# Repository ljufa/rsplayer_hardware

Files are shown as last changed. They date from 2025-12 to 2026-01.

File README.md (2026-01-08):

# RSPlayer Hardware

This repository contains the hardware design files for the RSPlayer project, a high-quality audio player. The designs are created in KiCad.

## Design Philosophy

This hardware design prioritizes **modularity** and **DIY-friendliness**. The goal is to provide a flexible platform where enthusiasts can easily swap components, upgrade specific subsystems (like power regulators or output stages), and experiment with different configurations. This open architecture encourages users to tweak the design, test new ideas, and continuously improve the audio performance to match their personal preferences.

## Boards
This repository is structured into several directories, each containing a specific board or a set of related files:

- **control_board_with_amanero**: A control board featuring an Amanero Combo768 USB interface.
- **lpf_ak4497**: Low-pass filter boards designed for the AK4497 DAC datasheet schematics. It includes designs for both `dual` and `dual_mono` configurations.
- [**LT3045_breakout**](https://github.com/PatrickBaus/LT3045_breakout.git): A modular breakout board for LT3042/LT3045 ultra-low noise regulators, used as drop-in replacements for 78xx series regulators.
- [**rsplayer_hardware_docs_private**](https://github.com/ljufa/rsplayer_hardware_docs_private.git): Contains external datasheets for various components used in the project. (this is private due to copyright)
- **MyLibrary.pretty**: A custom KiCad footprint library for this project.

## Features & Benefits

### Core Control & Interface
*   **MCU:** Powered by the **Raspberry Pi Pico (RP2040)**, providing robust system management, user interface control, and configuration logic. [**Firmware is here**](https://github.com/ljufa/rsplayer_firmware.git). 
*   **USB Audio:** Dedicated socket for **Amanero Combo384/Combo768** USB interfaces, supporting high-resolution PCM and DSD playback.
*   **User Interface:** Supports a Rotary Encoder for volume/navigation, IR Receiver (TSOP312) for remote control, and headers for LCD/OLED display integration.

### High-Fidelity Audio Design
*   **Galvanic Isolation:** Full isolation between the digital control logic (Pico/USB) and the sensitive DAC/Audio circuitry. Uses high-speed isolators (e.g., IL715E, ADuM1250) to eliminate ground loops and prevent digital noise from affecting audio quality.
*   **Hardware Muting:** Relay-based output muting protection to prevent audible pops and clicks during power cycles or sample rate changes.
*   **I2S Source Switching:** Features an intelligent I2S switching circuit using dual **74AC573** Octal Latches. This setup acts as a high-speed multiplexer, allowing seamless selection between the **Amanero USB interface (Source B)** and the **Optical/TOSLINK Input (Source A)**, controlled directly by the Raspberry Pi Pico.
*   **I2S & DSD Support:** Native handling of I2S and DSD signals routed directly to the DAC interface.

### Advanced Power Management
*   **Ultra-Low Noise Regulation:** Critically sensitive DAC stages are powered by modular **LT3042/LT3045** regulators. These are implemented as separate breakout boards (based on the `LT3045_breakout` design) acting as high-performance drop-in replacements for standard regulators, providing industry-leading low noise (0.8µVrms) and ultra-high PSRR.
*   **Multi-Rail Linear PSU:** On-board rectification and regulation generating separate clean rails for digital (3.3V), analog, and op-amp stages.
*   **Smart Power Control:** Relay-controlled AC mains switching allows for standby modes and remote power-on capabilities.

## Schematics
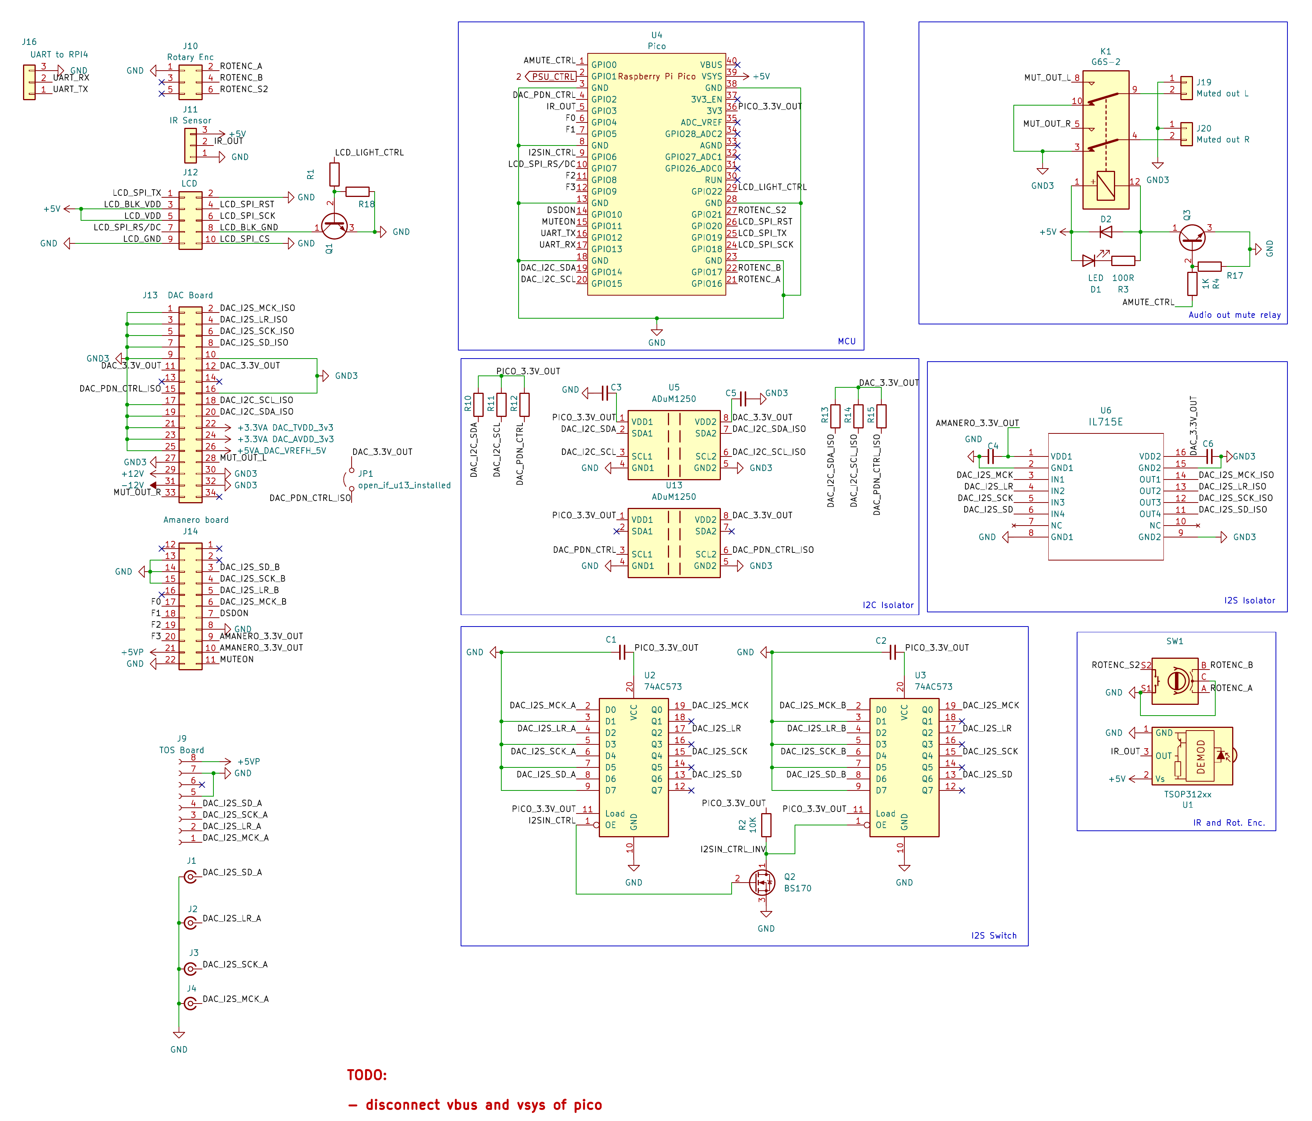
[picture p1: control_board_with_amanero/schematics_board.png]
Schematic Page 1

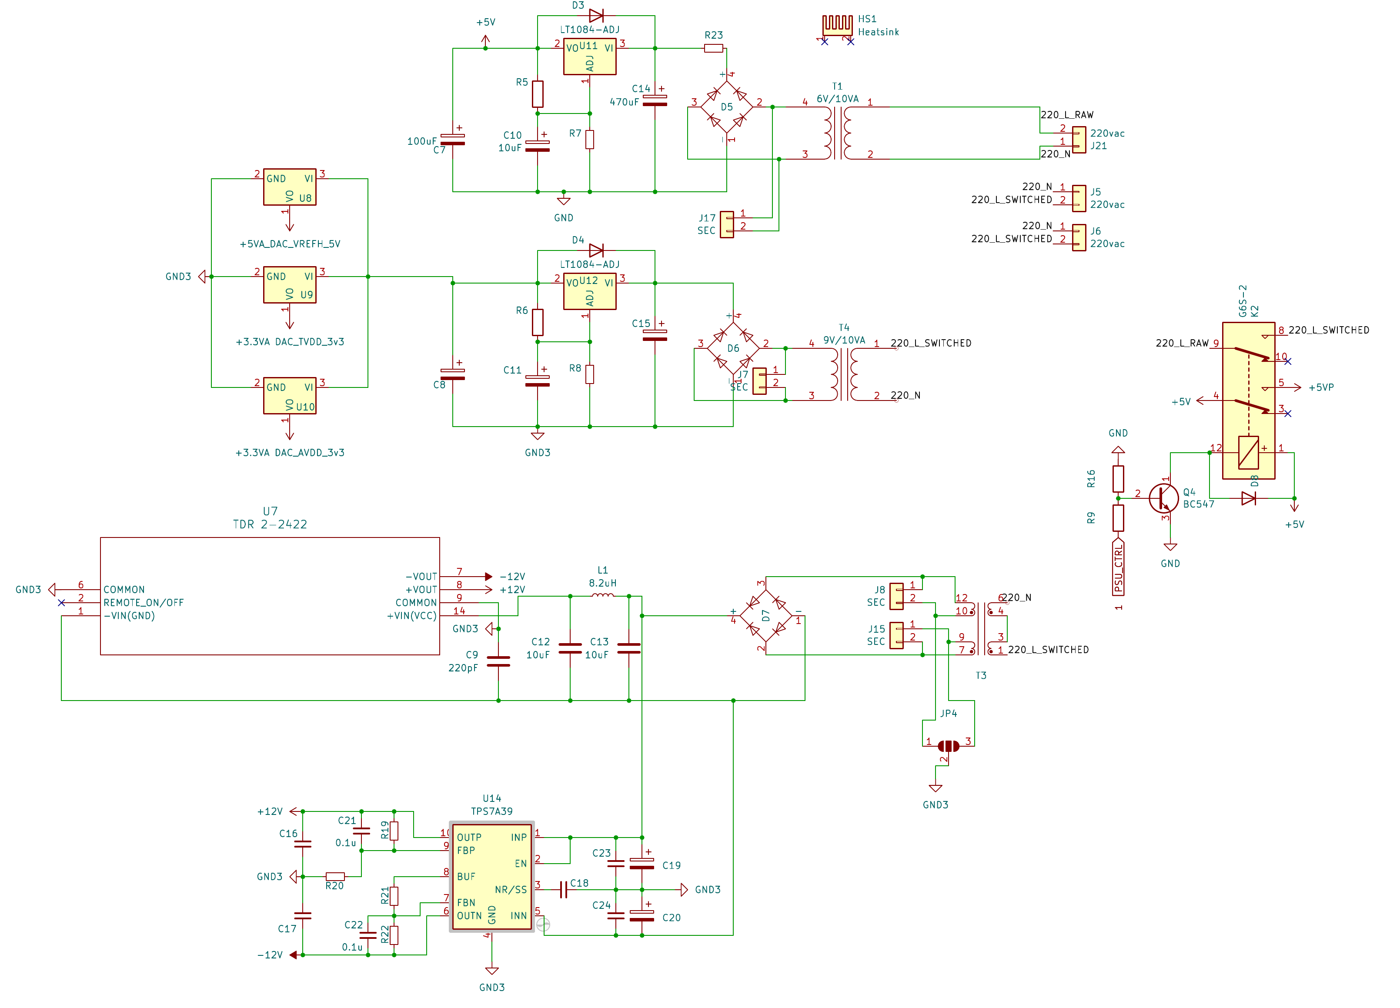
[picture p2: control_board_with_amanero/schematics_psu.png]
Schematic Page 2


## PCB
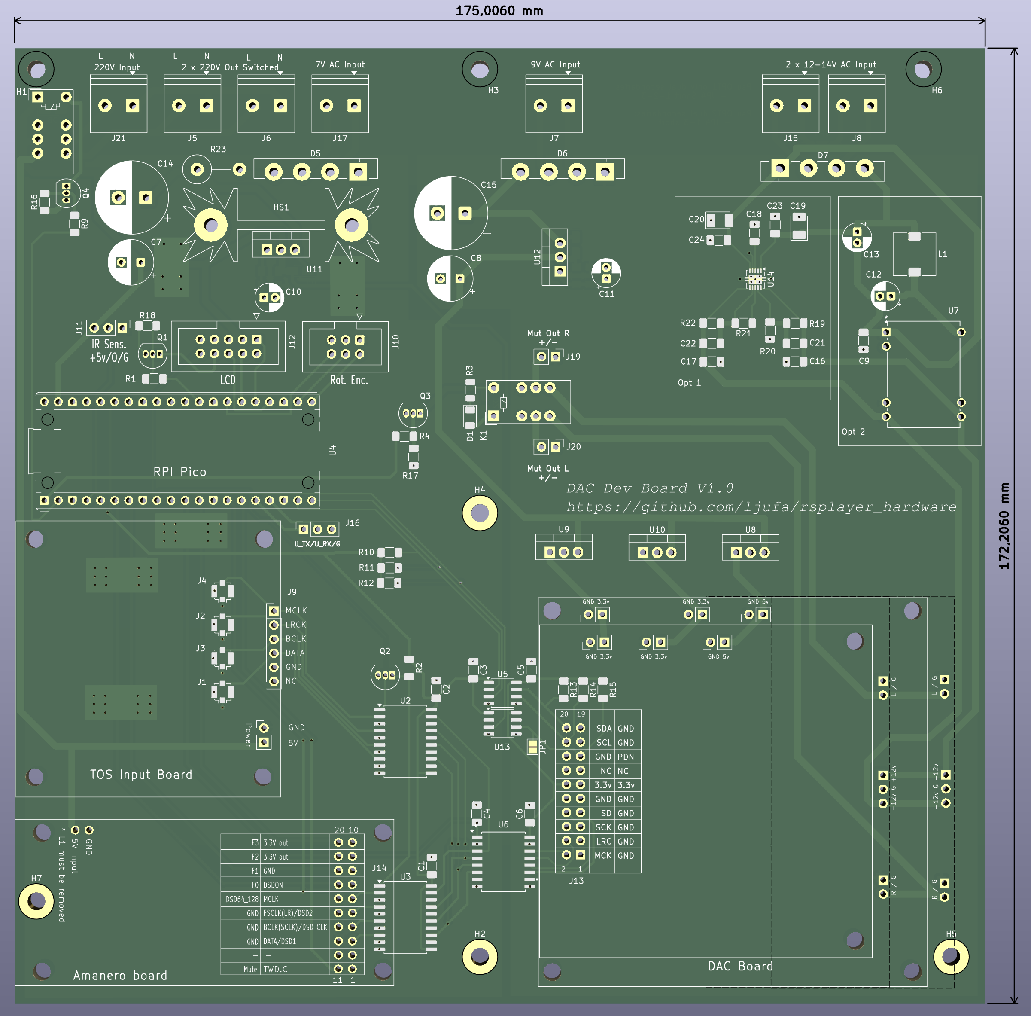
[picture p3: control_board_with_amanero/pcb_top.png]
top

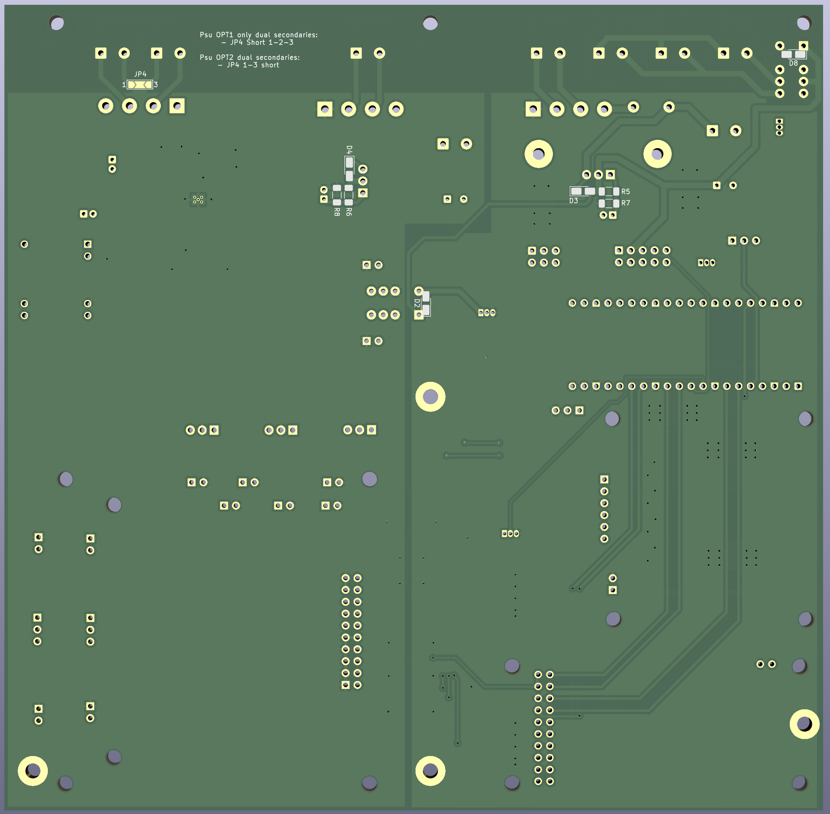
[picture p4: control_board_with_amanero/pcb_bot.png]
bottom

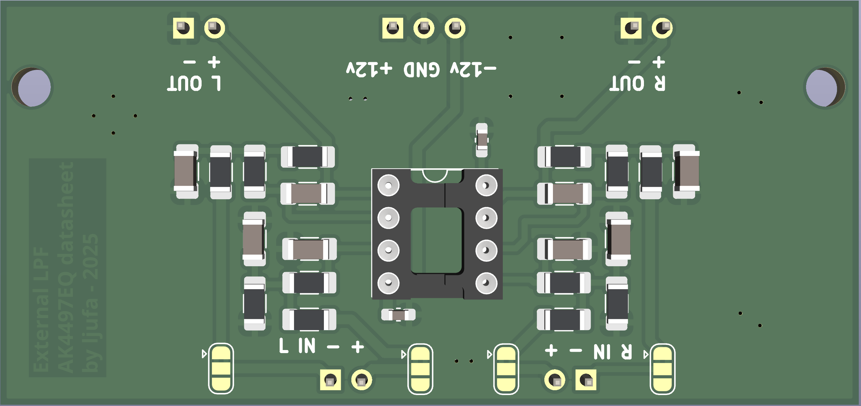
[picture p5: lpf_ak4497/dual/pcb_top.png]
lpf_top

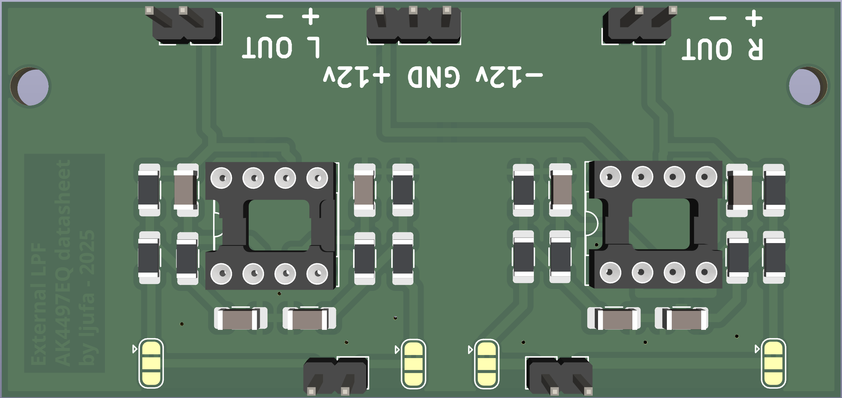
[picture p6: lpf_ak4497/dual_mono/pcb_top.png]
lpf_dm_top

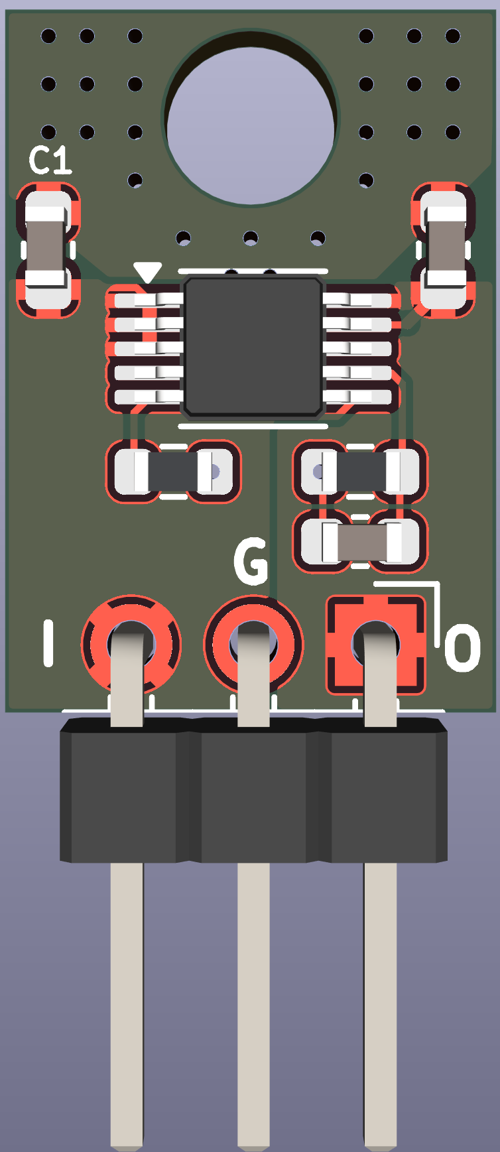
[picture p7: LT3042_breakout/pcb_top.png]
lt3042_top


## Future Roadmap
The project is evolving to become a universal high-fidelity audio platform. Planned improvements include:
*   **Expanded Interface Support:** Adding compatibility for additional **USB-to-I2S** boards beyond the Amanero series.
*   **Universal DAC Support:** Developing adapters and firmware logic to support a wider variety of **DAC chips and boards** (e.g., ESS Sabre, Burr-Brown), allowing users to choose their preferred sound signature.

## Related Projects
The RSPlayer is a multi-repository project:

- [**rsplayer**](https://github.com/ljufa/rsplayer.git): The main music player software running on PC or SBC.
- [**rsplayer_firmware**](https://github.com/ljufa/rsplayer_firmware.git): Firmware for MCU on this board. 

## License
This project is licensed under the MIT License. See the [LICENSE](LICENSE) file for details.

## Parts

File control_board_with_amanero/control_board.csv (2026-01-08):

Reference | Value | Qty
C1,C2,C3,C4,C5,C6,C21,C22,C23,C24 | 0.1u | 10
C7,C8 | 100uF | 2
C9 | 220pF | 1
C10,C11,C12,C13 | 10uF | 4
C14,C15 | 470uF | 2
C16,C17 | Value=22uF | 2
C18 | Value=10nF | 1
C19,C20 | Value=33uF Rser=350m | 2
D1 | LED | 1
D2,D3,D4,D8 | 1N4004 | 4
D5,D6,D7 | B80C3x00-2200A | 3
H1,H3,H6 | ~ | 3
HS1 | Heatsink | 1
J1,J2,J3,J4 | Conn_Coaxial_Small | 4
J5,J6,J21 | 220vac | 3
J7,J8,J15,J17 | SEC | 4
J9 | TOS Board | 1
J10 | Rotary Enc | 1
J11 | IR Sensor | 1
J12 | LCD | 1
J13 | DAC Board | 1
J14 | Amanero board | 1
J16 | UART to RPI4 | 1
J19 | Muted out L | 1
J20 | Muted out R | 1
JP1 | open_if_u13_installed | 1
K1,K2 | G6S-2 | 2
L1 | 8.2uH | 1
Q1,Q3,Q4 | BC547 | 3
Q2 | BS170 | 1
R1,R4,R9 | 1K | 3
R2,R10,R11,R12,R13,R14,R15,R16,R17,R18 | 10K | 10
R3,R5,R6 | 100R | 3
R7 | 300R | 1
R8 | 470R | 1
R19 | 90.9K | 1
R20,R21 | 10k | 2
R22 | 100k | 1
R23 | 0R | 1
SW1 | RotaryEncoder_Switch | 1
T1 | 6V/10VA | 1
T3 | Triad_VPP16-310 | 1
T4 | 9V/10VA | 1
U1 | TSOP312xx | 1
U2,U3 | 74AC573 | 2
U4 | Pico | 1
U5,U13 | ADuM1250 | 2
U6 | IL715E | 1
U7 | TDR 2-2422 | 1
U8,U9,U10 | lt3042_breakout | 3
U11,U12 | LT1084-ADJ | 2
U14 | TPS7A39 | 1

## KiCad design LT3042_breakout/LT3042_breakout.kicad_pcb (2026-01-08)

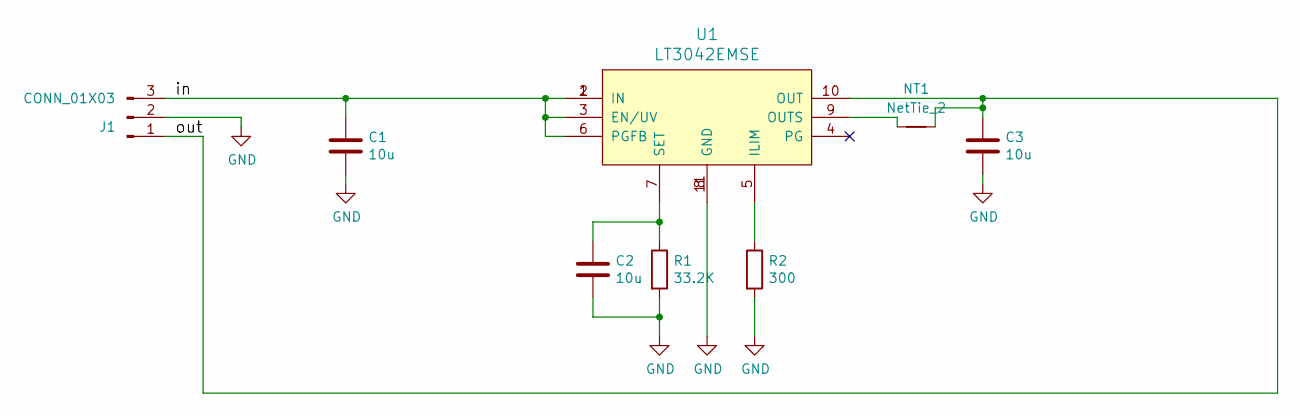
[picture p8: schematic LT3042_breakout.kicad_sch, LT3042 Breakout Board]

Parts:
C1, C2, C3: 10u; C_0603_1608Metric
J1: CONN_01X03; PinHeader_1x03_P2.54mm_Horizontal
NT1: NetTie_2; NetTie-2_SMD_Pad0.2mm
R1: 33.2K; R_0603_1608Metric
R2: 300; R_0603_1608Metric
U1: LT3042EMSE; MSOP-10-1EP_3x3mm_P0.5mm_EP1.68x1.88mm_ThermalVias

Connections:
/in: C1.1, J1.3, U1.1 (IN), U1.2 (IN), U1.3 (EN/UV), U1.6 (PGFB)
/out: C3.1, J1.1, NT1.2, U1.10 (OUT)
GND: C1.2, C2.2, C3.2, J1.2, R1.2, R2.2, U1.8 (GND), U1.11
unnamed: R2.1, U1.5 (ILIM)
unnamed: NT1.1, U1.9 (OUTS)
unnamed: C2.1, R1.1, U1.7 (SET)

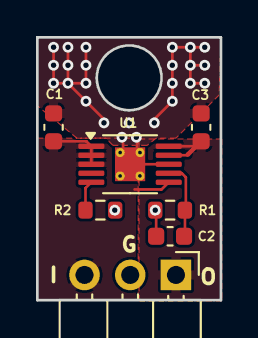
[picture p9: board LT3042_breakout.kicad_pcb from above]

Board: 2 copper layers, 10.2 x 14.6 mm, 8 parts (0 on the bottom side), 6 nets.

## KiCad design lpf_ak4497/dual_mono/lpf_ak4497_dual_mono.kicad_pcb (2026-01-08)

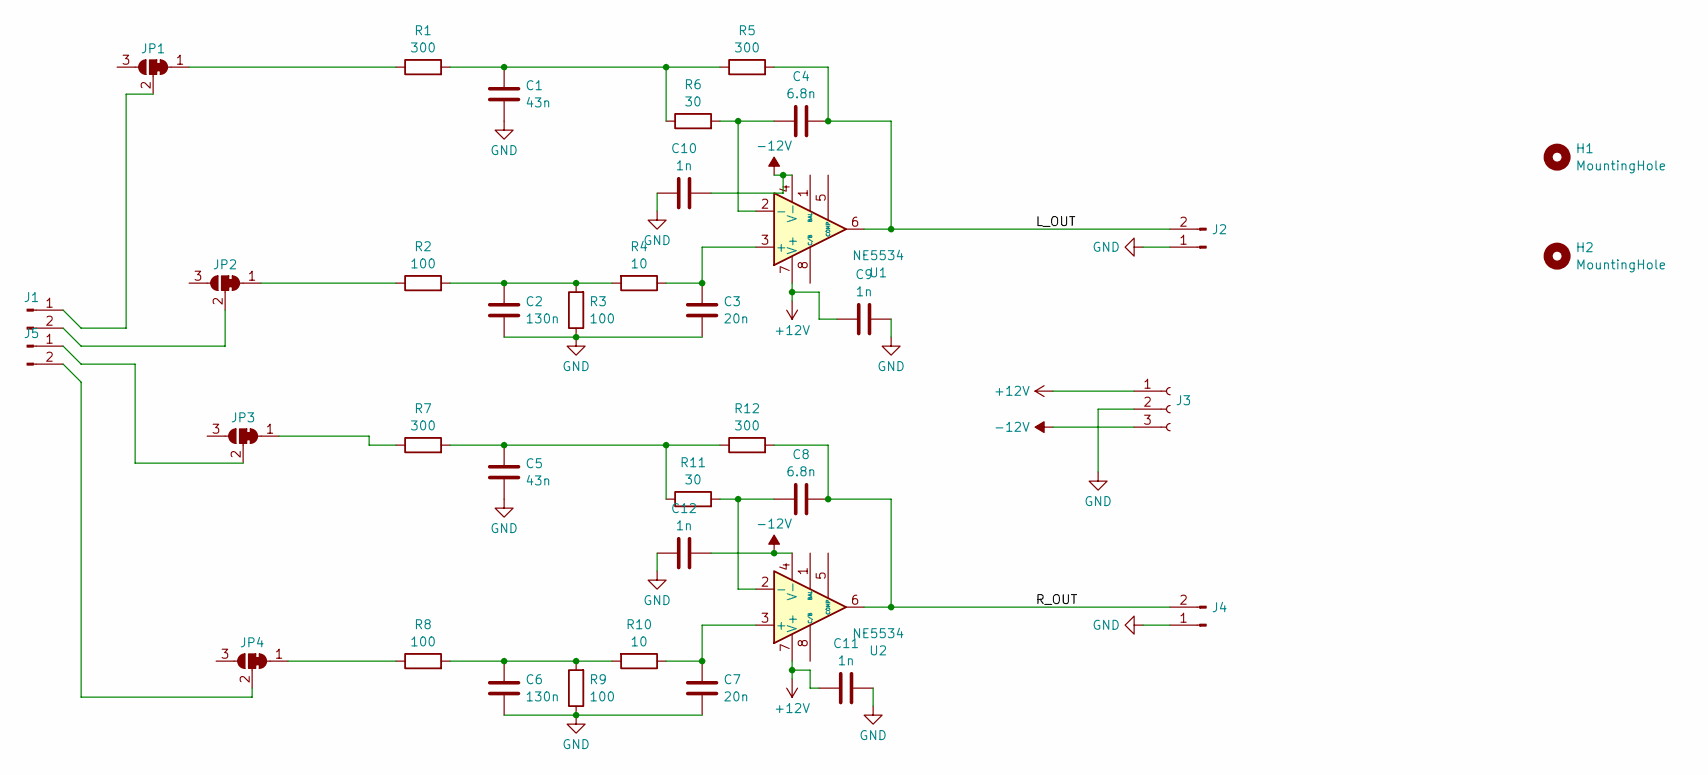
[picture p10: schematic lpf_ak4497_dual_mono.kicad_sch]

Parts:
C1, C5: 43n; C_1206_3216Metric_Pad1.33x1.80mm_HandSolder
C2, C6: 130n; C_1206_3216Metric_Pad1.33x1.80mm_HandSolder
C3, C7: 20n; C_1206_3216Metric_Pad1.33x1.80mm_HandSolder
C4, C8: 6.8n; C_1206_3216Metric_Pad1.33x1.80mm_HandSolder
C9, C10, C11, C12: 1n; C_0603_1608Metric_Pad1.08x0.95mm_HandSolder
H1, H2: MountingHole; MountingHole_3.2mm_M3
J1, J2, J4, J5: Conn_01x02_Pin; PinHeader_1x02_P2.54mm_Vertical
J3: Conn_01x03_Socket; PinHeader_1x03_P2.54mm_Vertical
JP1, JP2, JP3, JP4: SolderJumper-3_P1.3mm_Bridged2Bar12_RoundedPad1.0x1.5mm
R1, R5, R7, R12: 300; R_1206_3216Metric_Pad1.30x1.75mm_HandSolder
R2, R3, R8, R9: 100; R_1206_3216Metric_Pad1.30x1.75mm_HandSolder
R4, R10: 10; R_1206_3216Metric_Pad1.30x1.75mm_HandSolder
R6, R11: 30; R_1206_3216Metric_Pad1.30x1.75mm_HandSolder
U1, U2: NE5534; DIP-8_W7.62mm_Socket

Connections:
+12V: C9.2, C11.2, J3.1, U1.7 (V+), U2.7 (V+)
-12V: C10.1, C12.1, J3.3, U1.4 (V-), U2.4 (V-)
/L_OUT: C4.2, J2.2, R5.2, U1.6
/R_OUT: C8.2, J4.2, R12.2, U2.6
GND: C1.2, C2.2, C3.2, C5.2, C6.2, C7.2, C9.1, C10.2, C11.1, C12.2, J2.1, J3.2, J4.1, R3.1, R9.1
unnamed: C1.1, R1.2, R5.1, R6.1
unnamed: C2.1, R2.2, R3.2, R4.2
unnamed: C5.1, R7.2, R11.1, R12.1
unnamed: C6.1, R8.2, R9.2, R10.2
unnamed: J1.1, JP1.2 (C)
unnamed: J1.2, JP2.2 (C)
unnamed: J5.1, JP3.2 (C)
unnamed: J5.2, JP4.2 (C)
unnamed: JP1.1 (A), R1.1
unnamed: JP2.1 (A), R2.1
unnamed: JP3.1 (A), R7.1
unnamed: JP4.1 (A), R8.1
unnamed: C3.1, R4.1, U1.3 (+)
unnamed: C4.1, R6.2, U1.2 (-)
unnamed: C7.1, R10.1, U2.3 (+)
unnamed: C8.1, R11.2, U2.2 (-)

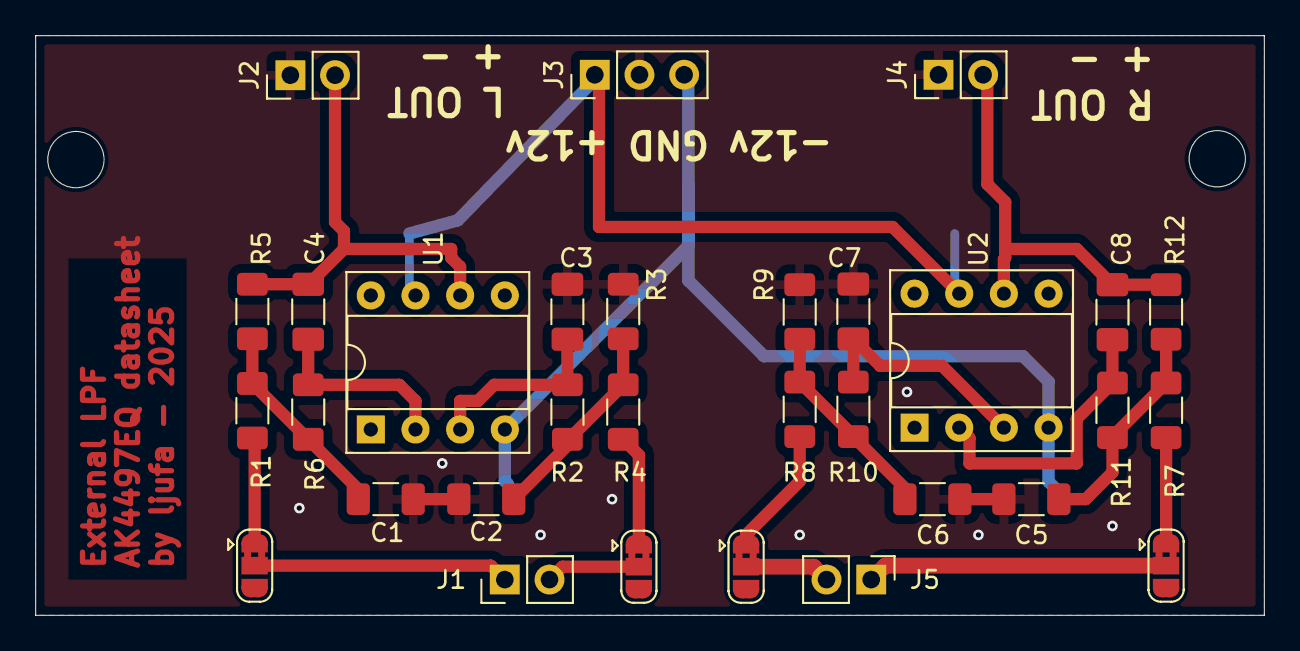
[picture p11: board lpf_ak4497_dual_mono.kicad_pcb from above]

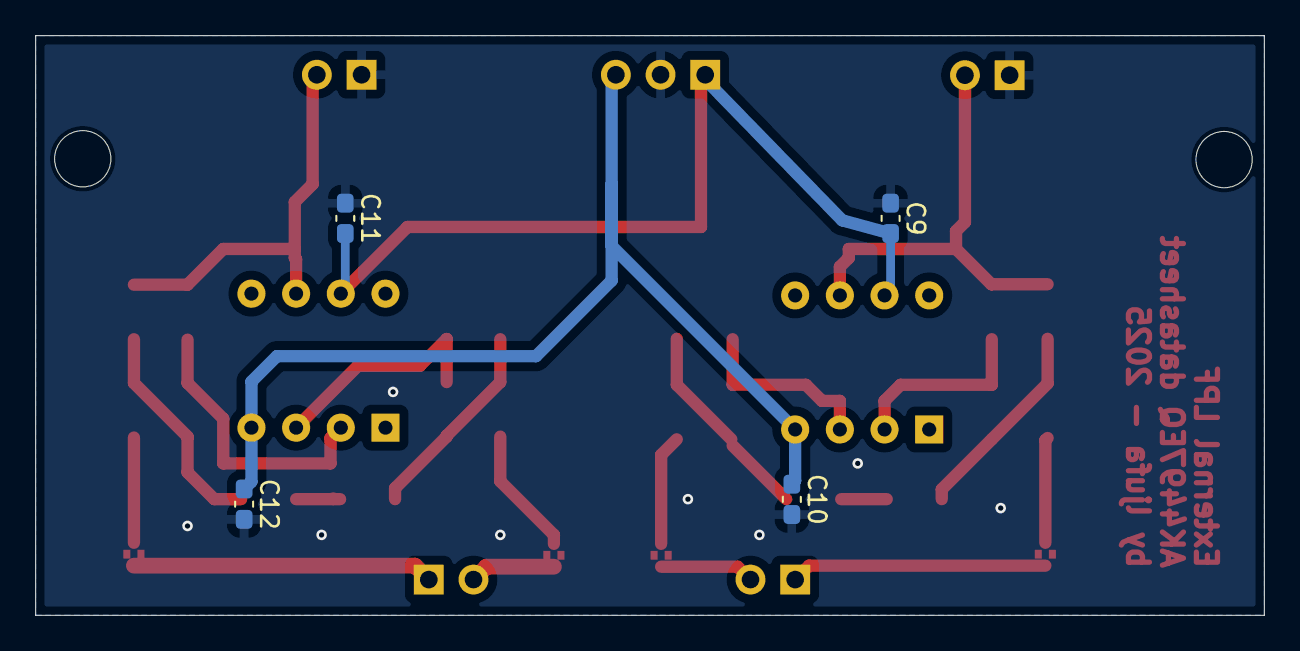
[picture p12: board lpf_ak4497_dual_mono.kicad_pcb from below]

Board: 2 copper layers, 69.9 x 33.0 mm, 37 parts (4 on the bottom side), 21 nets.

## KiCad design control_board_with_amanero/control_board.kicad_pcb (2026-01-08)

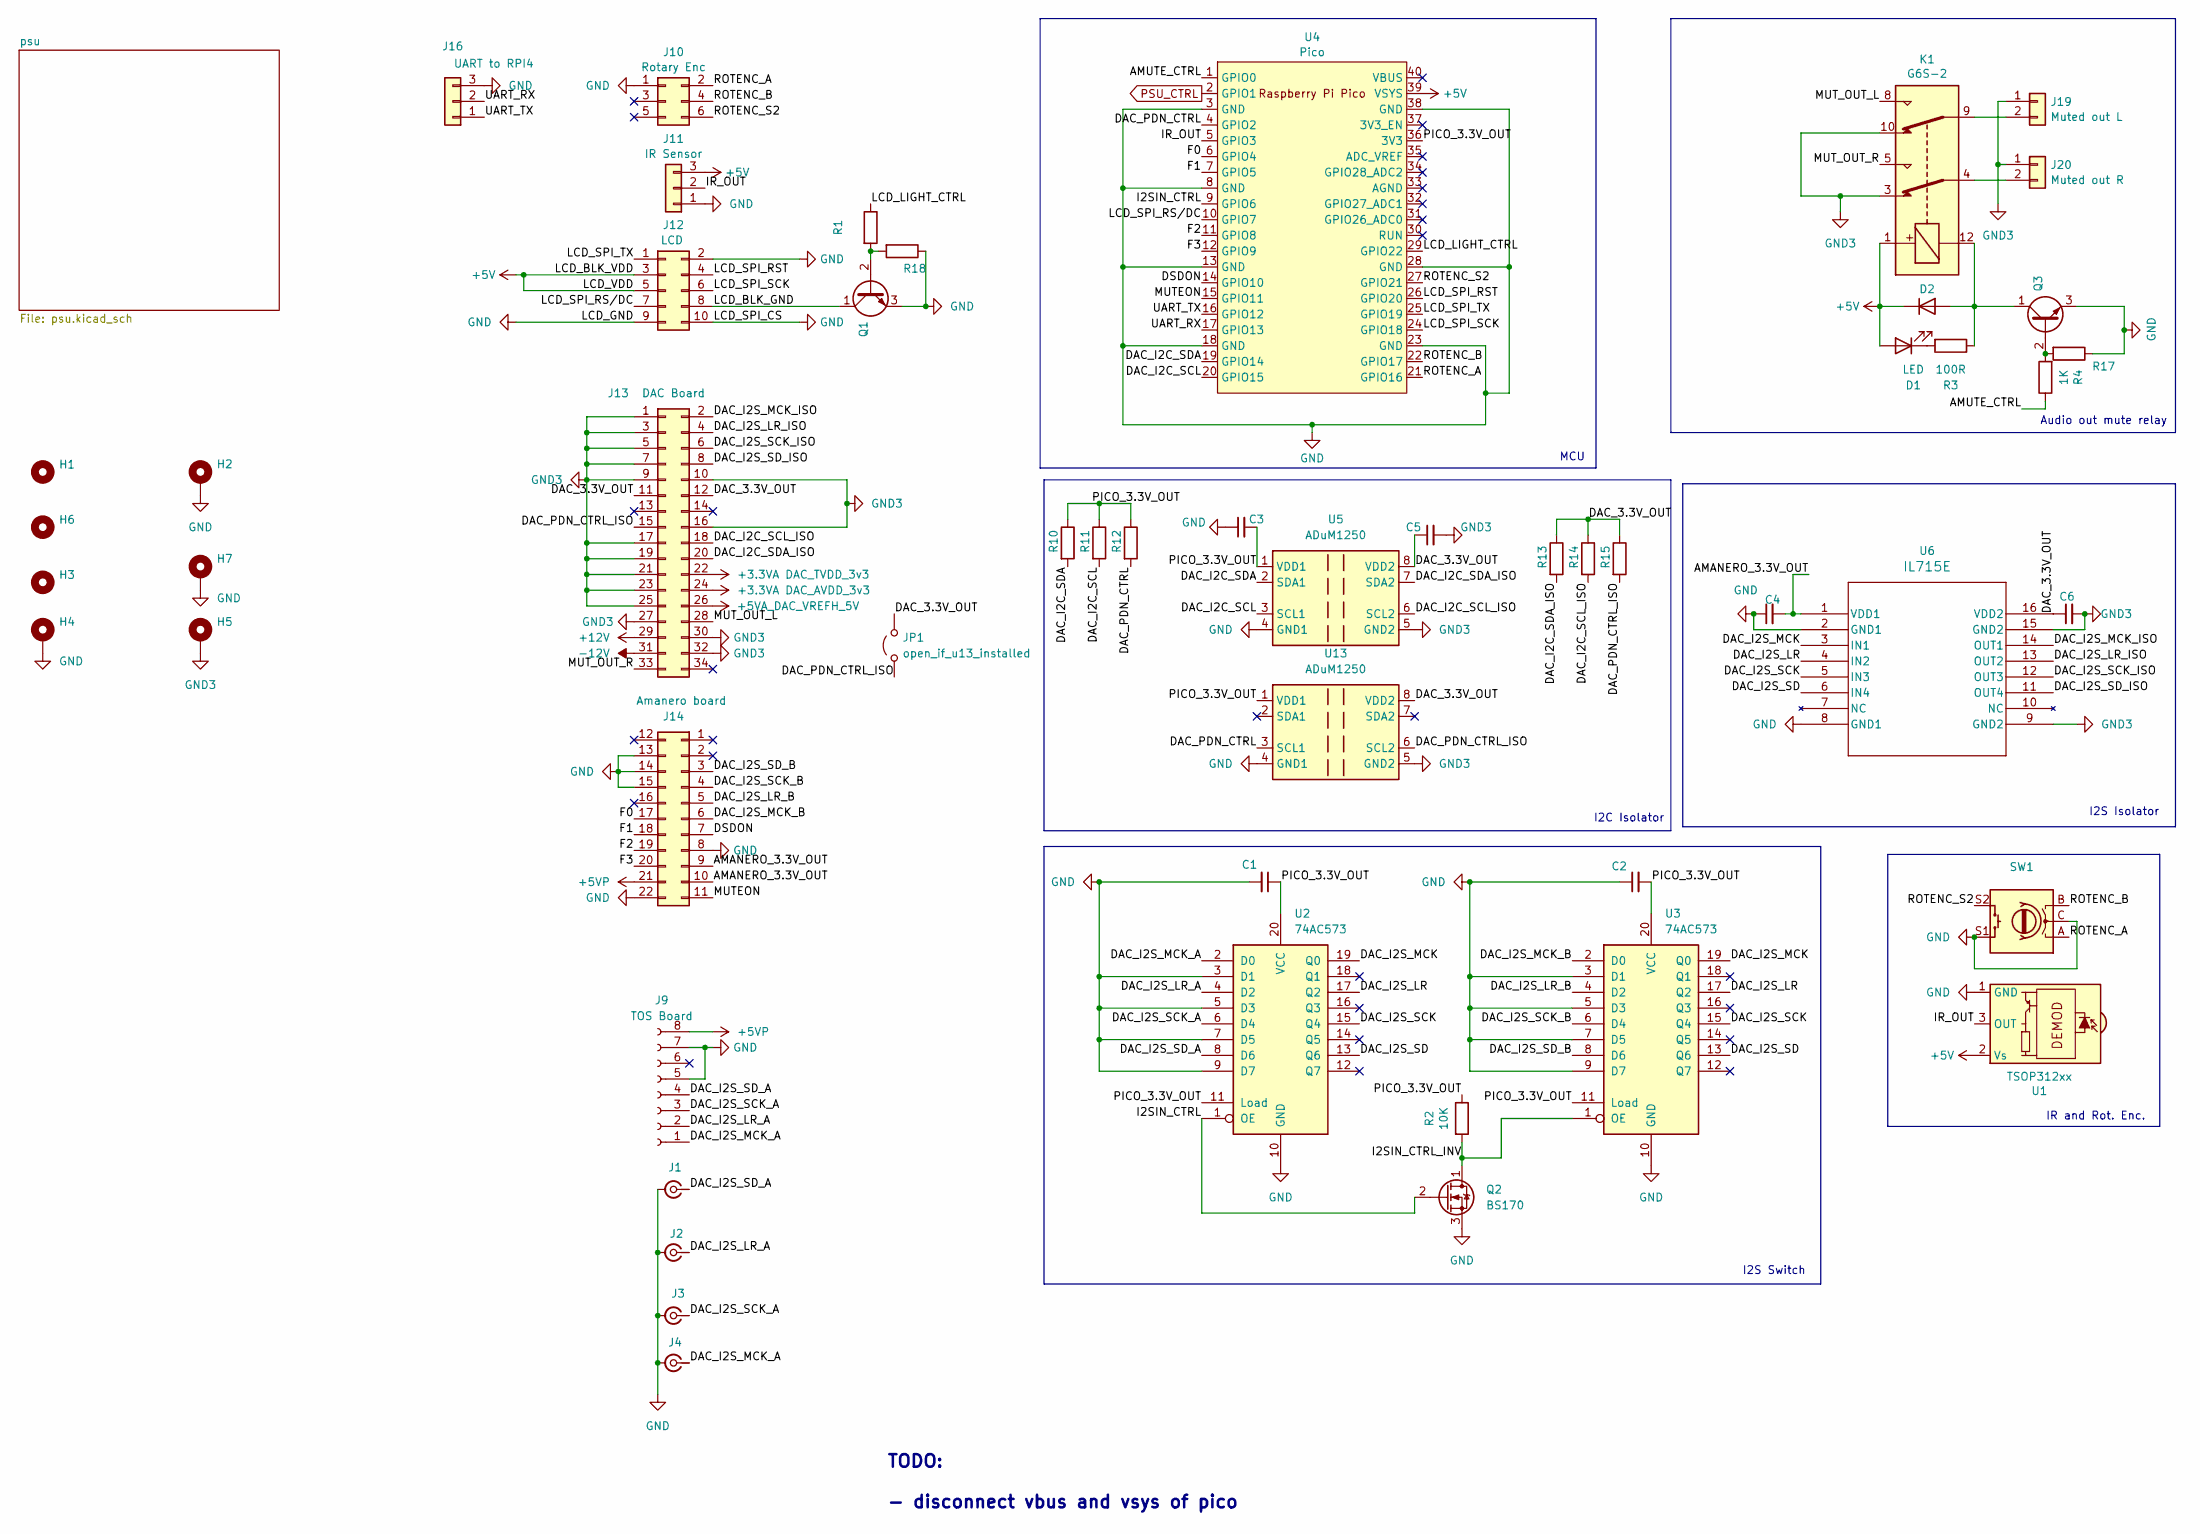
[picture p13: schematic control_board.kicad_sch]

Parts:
C1, C2, C3, C4, C5, C6: 0.1u; C_1206_3216Metric_Pad1.33x1.80mm_HandSolder
D1: LED; LED_1206_3216Metric
D2: 1N4004; D_MicroMELF_Handsoldering
H1, H3, H6: MountingHole_3.2mm_M3
H2, H4, H5, H7: MountingHole_3.2mm_M3_Pad_TopBottom
J1, J2, J3, J4: Conn_Coaxial_Small; U.FL_Molex_MCRF_73412-0110_Vertical
J9: TOS Board; tosInputBoard
J10: Rotary Enc; IDC-Header_2x03_P2.54mm_Vertical
J11: IR Sensor; PinHeader_1x03_P2.54mm_Vertical
J12: LCD; IDC-Header_2x05_P2.54mm_Vertical
J13: DAC Board; diyinkhak4490+4497board
J14: Amanero board; Amanero Combo768
J16: UART to RPI4; PinSocket_1x03_P2.54mm_Vertical
J19: Muted out L; PinHeader_1x02_P2.54mm_Vertical
J20: Muted out R; PinHeader_1x02_P2.54mm_Vertical
JP1: open_if_u13_installed; SolderJumper-2_P1.3mm_Open_Pad1.0x1.5mm
K1: G6S-2; Relay_DPDT_Omron_G6S-2
Q1, Q3: BC547; TO-92_Inline
Q2: BS170; TO-92_Inline
R1, R4: 1K; R_1206_3216Metric_Pad1.30x1.75mm_HandSolder
R2, R10, R11, R12, R13, R14, R15, R17, R18: 10K; R_1206_3216Metric_Pad1.30x1.75mm_HandSolder
R3: 100R; R_1206_3216Metric
SW1: RotaryEncoder_Switch
U1: TSOP312xx; Vishay_CAST-3Pin
U2, U3: 74AC573; SOIC-20W_7.5x12.8mm_P1.27mm
U4: Pico; RaspberryPi_Pico_Common_THT
U5, U13: ADuM1250; SOIC-8_3.9x4.9mm_P1.27mm
U6: IL715E; SOIC16_WIDE_NVE

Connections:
+3.3VA DAC_AVDD_3v3: J13.24; also elsewhere on the board
+3.3VA DAC_TVDD_3v3: J13.22; also elsewhere on the board
+5V: D1.2 (A), D2.1 (K), J11.3, J12.3, J12.5, K1.1, U4.39 (VSYS); also elsewhere on the board
+5VA_DAC_VREFH_5V: J13.26; also elsewhere on the board
+5VP: J9.8, J14.21; also elsewhere on the board
+12V: J13.29; also elsewhere on the board
-12V: J13.31; also elsewhere on the board
/AMANERO_3.3V_OUT: C4.2, J14.9, J14.10, U6.1 (VDD1)
/AMUTE_CTRL: R4.1, U4.1 (GPIO0)
/DAC_3.3V_OUT: C5.1, C6.1, J13.11, J13.12, JP1.2 (B), R13.1, R14.1, R15.1, U5.8 (VDD2), U6.16 (VDD2), U13.8 (VDD2)
/DAC_I2C_SCL: R11.2, U4.20 (GPIO15), U5.3 (SCL1)
/DAC_I2C_SCL_ISO: J13.18, R14.2, U5.6 (SCL2)
/DAC_I2C_SDA: R10.2, U4.19 (GPIO14), U5.2 (SDA1)
/DAC_I2C_SDA_ISO: J13.20, R13.2, U5.7 (SDA2)
/DAC_I2S_LR: U2.17 (Q2), U3.17 (Q2), U6.4 (IN2)
/DAC_I2S_LR_A: J2.1 (In), J9.2, U2.4 (D2)
/DAC_I2S_LR_B: J14.5, U3.4 (D2)
/DAC_I2S_LR_ISO: J13.4, U6.13 (OUT2)
/DAC_I2S_MCK: U2.19 (Q0), U3.19 (Q0), U6.3 (IN1)
/DAC_I2S_MCK_A: J4.1 (In), J9.1, U2.2 (D0)
/DAC_I2S_MCK_B: J14.6, U3.2 (D0)
/DAC_I2S_MCK_ISO: J13.2, U6.14 (OUT1)
/DAC_I2S_SCK: U2.15 (Q4), U3.15 (Q4), U6.5 (IN3)
/DAC_I2S_SCK_A: J3.1 (In), J9.3, U2.6 (D4)
/DAC_I2S_SCK_B: J14.4, U3.6 (D4)
/DAC_I2S_SCK_ISO: J13.6, U6.12 (OUT3)
/DAC_I2S_SD: U2.13 (Q6), U3.13 (Q6), U6.6 (IN4)
/DAC_I2S_SD_A: J1.1 (In), J9.4, U2.8 (D6)
/DAC_I2S_SD_B: J14.3, U3.8 (D6)
/DAC_I2S_SD_ISO: J13.8, U6.11 (OUT4)
/DAC_PDN_CTRL: R12.2, U4.4 (GPIO2), U13.3 (SCL1)
/DAC_PDN_CTRL_ISO: J13.15, JP1.1 (A), R15.2, U13.6 (SCL2)
/DSDON: J14.7, U4.14 (GPIO10)
/F0: J14.17, U4.6 (GPIO4)
/F1: J14.18, U4.7 (GPIO5)
/F2: J14.19, U4.11 (GPIO8)
/F3: J14.20, U4.12 (GPIO9)
/I2SIN_CTRL: Q2.2 (G), U2.1 (OE), U4.9 (GPIO6)
/I2SIN_CTRL_INV: Q2.1 (D), R2.2, U3.1 (OE)
/IR_OUT: J11.2, U4.5 (GPIO3)
/LCD_BLK_GND: J12.8, Q1.1 (C)
/LCD_LIGHT_CTRL: R1.1, U4.29 (GPIO22)
/LCD_SPI_RST: J12.4, U4.26 (GPIO20)
/LCD_SPI_RS/DC: J12.7, U4.10 (GPIO7)
/LCD_SPI_SCK: J12.6, U4.24 (GPIO18)
/LCD_SPI_TX: J12.1, U4.25 (GPIO19)
/MUTEON: J14.11, U4.15 (GPIO11)
/MUT_OUT_L: J13.28, K1.8
/MUT_OUT_R: J13.33, K1.5
/PICO_3.3V_OUT: C1.1, C2.2, C3.2, R2.1, R10.1, R11.1, R12.1, U2.11 (Load), U2.20 (VCC), U3.11 (Load), U3.20 (VCC), U4.36 (3V3), U5.1 (VDD1), U13.1 (VDD1)
/ROTENC_A: J10.2, U4.21 (GPIO16)
/ROTENC_B: J10.4, SW1.B, U4.22 (GPIO17); also elsewhere on the board
/ROTENC_S2: J10.6, SW1.S2, U4.27 (GPIO21); also elsewhere on the board
/UART_RX: J16.2, U4.17 (GPIO13)
/UART_TX: J16.1, U4.16 (GPIO12)
GND: C1.2, C2.1, C3.1, C4.1, H2.1, H4.1, H7.1, J1.2 (Ext), J2.2 (Ext), J3.2 (Ext), J4.2 (Ext), J9.5, J9.7, J10.1, J11.1, J12.2, J12.9, J12.10, J14.8, J14.13, J14.14, J14.15, J14.22, J16.3, Q1.3 (E), Q2.3 (S), Q3.3 (E), R17.1, R18.1, U2.3 (D1), U2.5 (D3), U2.7 (D5), U2.9 (D7), U2.10 (GND), U3.3 (D1), U3.5 (D3), U3.7 (D5), U3.9 (D7), U3.10 (GND), U4.3 (GND), U4.8 (GND), U4.13 (GND), U4.18 (GND), U4.23 (GND), U4.28 (GND), U4.38 (GND), U5.4 (GND1), U6.2 (GND1), U6.8 (GND1), U13.4 (GND1); also elsewhere on the board
GND3: C5.2, C6.2, H5.1, J13.1, J13.3, J13.5, J13.7, J13.9, J13.10, J13.16, J13.17, J13.19, J13.21, J13.23, J13.25, J13.27, J13.30, J13.32, J19.1, J20.1, K1.3, K1.10, U5.5 (GND2), U6.9 (GND2), U6.15 (GND2), U13.5 (GND2); also elsewhere on the board
unnamed: D1.1 (K), R3.2
unnamed: D2.2 (A), K1.12, Q3.1 (C), R3.1
unnamed: J19.2, K1.9
unnamed: J20.2, K1.4
unnamed: Q1.2 (B), R1.2, R18.2
unnamed: Q3.2 (B), R4.2, R17.2
PSU_CTRL: U4.2 (GPIO1); also elsewhere on the board

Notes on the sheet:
IR and Rot. Enc.
I2C Isolator
Audio out mute relay
MCU
I2S Isolator
I2S Switch
TODO: - disconnect vbus and vsys of pico

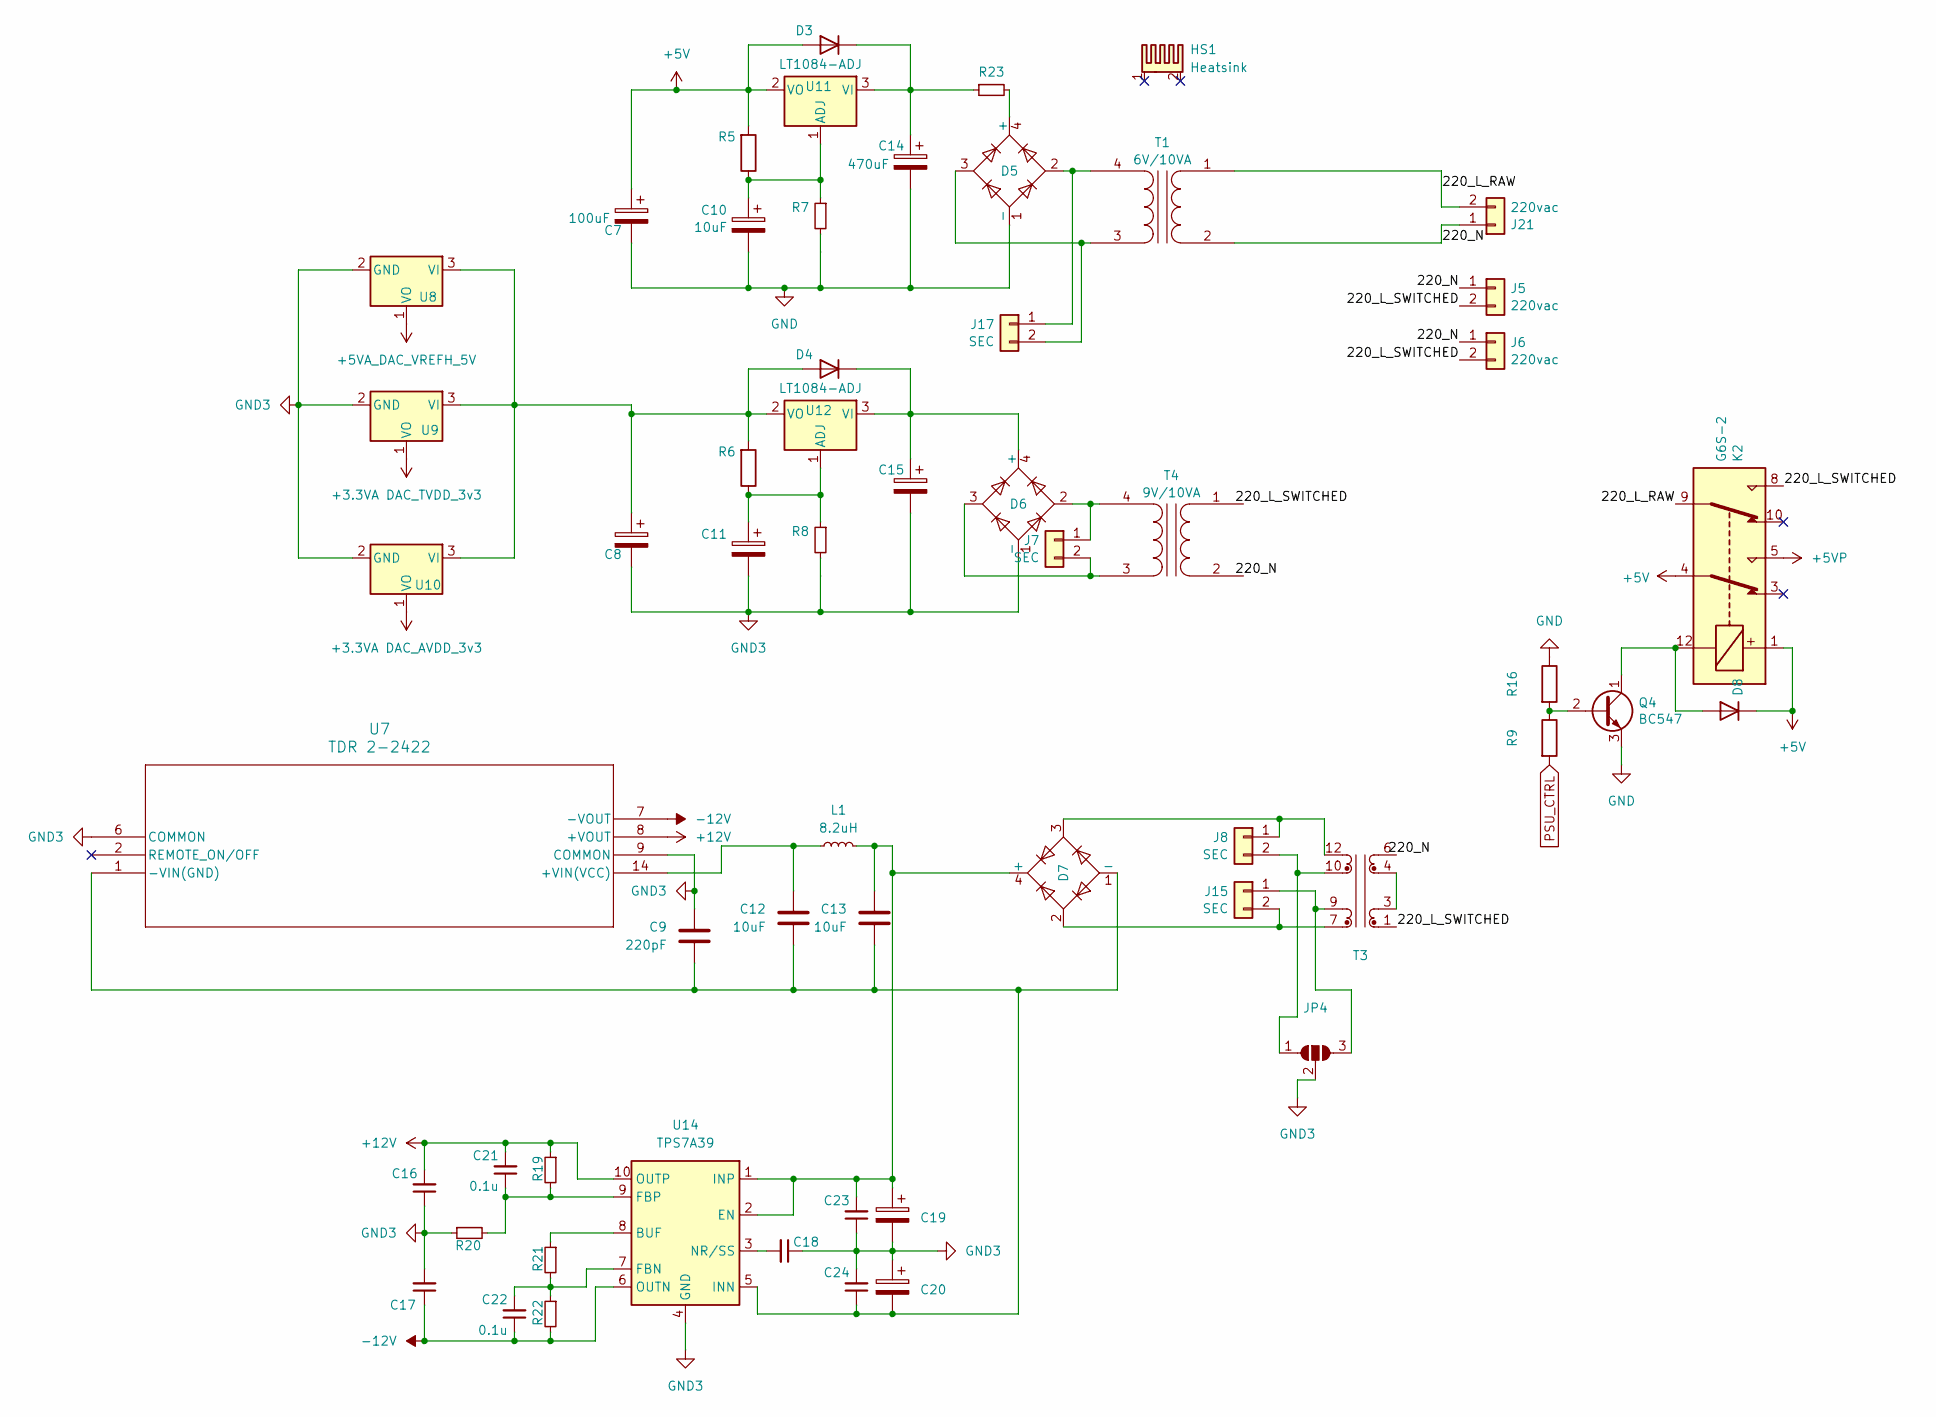
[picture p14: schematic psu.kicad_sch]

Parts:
C7, C8: 100uF; CP_Radial_D8.0mm_P3.50mm
C9: 220pF; C_1206_3216Metric_Pad1.33x1.80mm_HandSolder
C10, C11, C12, C13: 10uF; CP_Radial_D5.0mm_P2.00mm
C14, C15: 470uF; CP_Radial_D13.0mm_P5.00mm
C16, C17: Value=22uF; C_1206_3216Metric_Pad1.33x1.80mm_HandSolder
C18: Value=10nF; C_1206_3216Metric_Pad1.33x1.80mm_HandSolder
C19, C20: Value=33uF Rser=350m; CP_EIA-3528-21_Kemet-B_HandSolder
C21, C22, C23, C24: 0.1u; C_1206_3216Metric_Pad1.33x1.80mm_HandSolder
D3, D4, D8: 1N4004; D_MicroMELF_Handsoldering
D5, D6, D7: B80C3x00-2200A; Diode_Bridge_Vishay_GBU
HS1: Heatsink; Heatsink_Fischer_SK104-STC-STIC_35x13mm_2xDrill2.5mm
J5, J6, J21: 220vac; TerminalBlock_Philmore_TB132_1x02_P5.00mm_Horizontal
J7, J8, J15, J17: SEC; TerminalBlock_Philmore_TB132_1x02_P5.00mm_Horizontal
JP4: SolderJumper_3_Open; SolderJumper-3_P2.0mm_Open_TrianglePad1.0x1.5mm_NumberLabels
K2: G6S-2; Relay_DPDT_Omron_G6S-2
L1: 8.2uH; L_SXN_SMDRI73
Q4: BC547; TO-92_Inline
R5, R6: 100R; R_1206_3216Metric_Pad1.30x1.75mm_HandSolder
R7: 300R; R_1206_3216Metric_Pad1.30x1.75mm_HandSolder
R8: 470R; R_1206_3216Metric_Pad1.30x1.75mm_HandSolder
R9: 1K; R_1206_3216Metric_Pad1.30x1.75mm_HandSolder
R16: 10K; R_1206_3216Metric_Pad1.30x1.75mm_HandSolder
R19: 90.9K; R_1206_3216Metric_Pad1.30x1.75mm_HandSolder
R20, R21: 10k; R_1206_3216Metric_Pad1.30x1.75mm_HandSolder
R22: 100k; R_1206_3216Metric_Pad1.30x1.75mm_HandSolder
R23: 0R; R_Axial_DIN0516_L15.5mm_D5.0mm_P7.62mm_Vertical
T1: 6V/10VA; MYRRA_44266
T3: Triad_VPP16-310; Transformer_Murata_PL10-28-130B
T4: 9V/10VA; MYRRA_44266
U7: TDR 2-2422; TDR 2 DUAL_TRP
U8, U9, U10: lt3042_breakout; TO-220-3_Vertical
U11, U12: LT1084-ADJ; TO-220-3_Vertical
U14: TPS7A39; Texas_S-PVSON-N10_ThermalVias

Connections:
+3.3VA DAC_AVDD_3v3: U10.1 (VO); also elsewhere on the board
+3.3VA DAC_TVDD_3v3: U9.1 (VO); also elsewhere on the board
+5V: C7.1, D3.2 (A), D8.1 (K), K2.1, K2.4, R5.2, U11.2 (VO); also elsewhere on the board
+5VA_DAC_VREFH_5V: U8.1 (VO); also elsewhere on the board
+5VP: K2.5; also elsewhere on the board
+12V: C16.2, C21.2, R19.1, U7.8 (+VOUT), U14.10 (OUTP); also elsewhere on the board
-12V: C17.1, C22.1, R22.2, U7.7 (-VOUT), U14.6 (OUTN); also elsewhere on the board
/psu/220_L_RAW: J21.2, K2.9, T1.1 (AA)
/psu/220_L_SWITCHED: J5.2, J6.2, K2.8, T3.1
/psu/220_N: J5.1, J6.1, J21.1, T1.2 (AB)
GND: C7.2, C10.2, C14.2, D5.1 (-), Q4.3 (E), R7.2, R16.1; also elsewhere on the board
GND3: C8.2, C9.1, C11.2, C15.2, C16.1, C17.2, C18.1, C19.2, C20.1, C23.1, C24.2, D6.1 (-), JP4.2 (C), R8.2, R20.1, U7.6 (COMMON), U7.9 (COMMON), U8.2 (GND), U9.2 (GND), U10.2 (GND), U14.4 (GND), U14.11 (GND); also elsewhere on the board
unnamed: C14.1, D3.1 (K), R23.1, U11.3 (VI)
unnamed: C8.1, D4.2 (A), R6.2, U8.3 (VI), U9.3 (VI), U10.3 (VI), U12.2 (VO)
unnamed: C15.1, D4.1 (K), D6.4 (+), U12.3 (VI)
unnamed: D5.4 (+), R23.2
unnamed: C13.1, C19.1, C23.2, D7.4 (+), L1.1, U14.1 (INP), U14.2 (EN)
unnamed: C9.2, C12.2, C13.2, C20.2, C24.1, D7.1 (-), U7.1 (-VIN(GND)), U14.5 (INN)
unnamed: D8.2 (A), K2.12, Q4.1 (C)
unnamed: D6.2, J7.1, T4.4 (SB)
unnamed: D6.3, J7.2, T4.3 (SA)
unnamed: D7.3, J8.1, T3.12
unnamed: J8.2, JP4.1 (A), T3.10
unnamed: J15.1, JP4.3 (B), T3.9
unnamed: D7.2, J15.2, T3.7
unnamed: D5.2, J17.1, T1.4 (SB)
unnamed: D5.3, J17.2, T1.3 (SA)
unnamed: Q4.2 (B), R9.1, R16.2
unnamed: T3.3, T3.4
unnamed: C12.1, L1.2, U7.14 (+VIN(VCC))
unnamed: C10.1, R5.1, R7.1, U11.1 (ADJ)
unnamed: C11.1, R6.1, R8.1, U12.1 (ADJ)
unnamed: R21.1, U14.8 (BUF)
unnamed: C22.2, R21.2, R22.1, U14.7 (FBN)
unnamed: C21.1, R19.2, R20.2, U14.9 (FBP)
unnamed: C18.2, U14.3 (NR/SS)
PSU_CTRL: R9.2; also elsewhere on the board

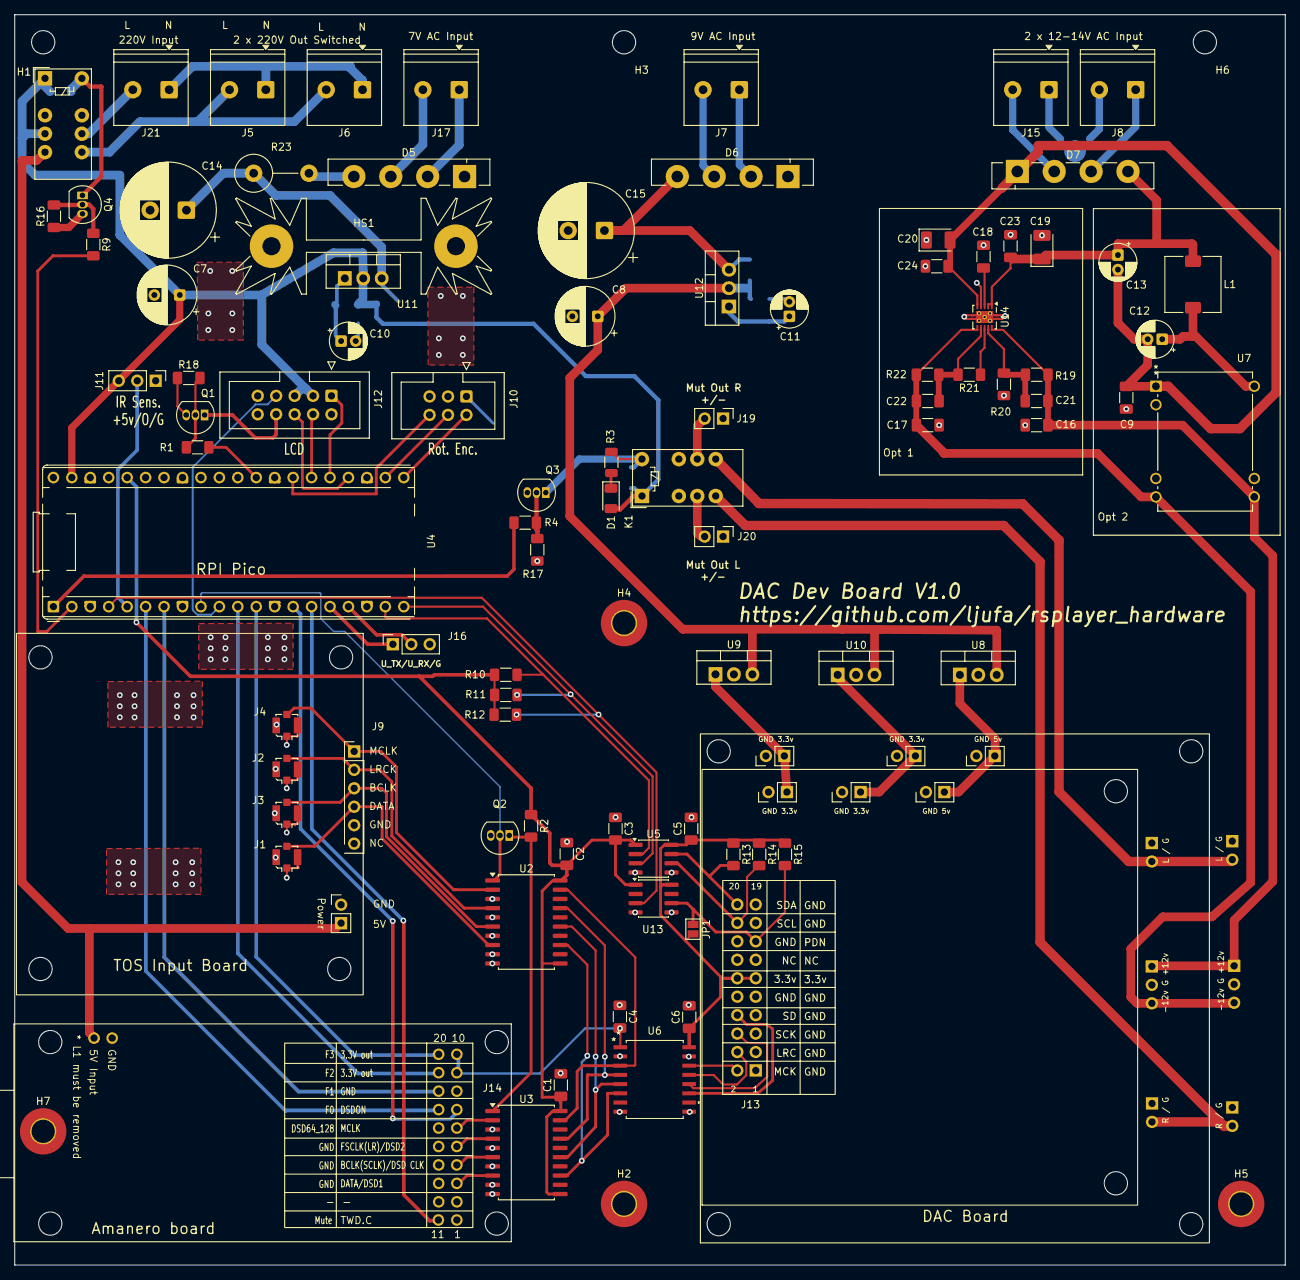
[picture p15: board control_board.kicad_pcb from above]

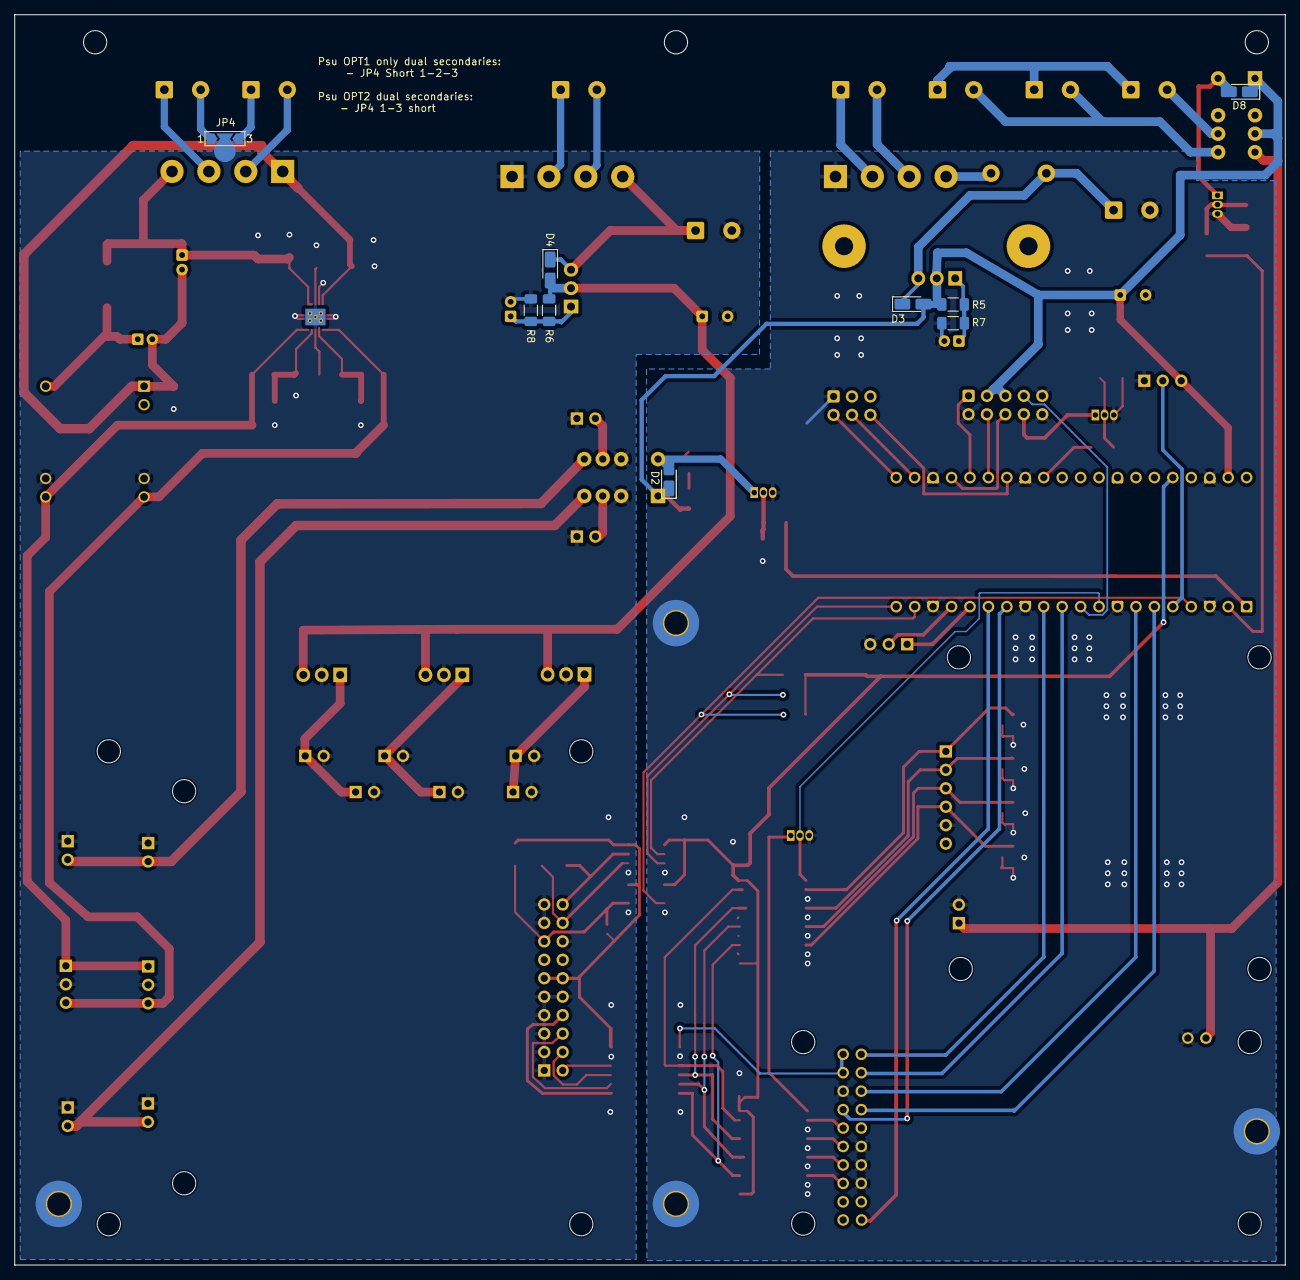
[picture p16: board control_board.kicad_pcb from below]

Board: 2 copper layers, 175.0 x 172.2 mm, 105 parts (9 on the bottom side), 90 nets.

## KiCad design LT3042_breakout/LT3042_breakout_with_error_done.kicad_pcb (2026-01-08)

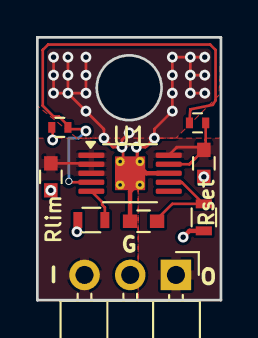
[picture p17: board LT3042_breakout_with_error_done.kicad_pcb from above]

Board: 2 copper layers, 10.2 x 14.6 mm, 10 parts (0 on the bottom side), 7 nets.

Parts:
C1, C2, C3: 10u; C_0603
J1: CONN_01X03; Pin_Header_Angled_1x03_Pitch2.54mm
R1: 33.2K; R_0603
R2: 300; R_0603
R3: 200k; R_0402
R4: 5.6k; R_0402
U1: LT3045EDD; MSOP-10-1EP_3x3mm_P0.5mm_EP1.68x1.88mm_ThermalVias
W1: NET-TIE; NET-TIE-0.15mm

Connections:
/in: C1.1, J1.3, U1.1 (IN), U1.2 (IN), U1.3 (EN/UV)
/out: C3.1, J1.1, R3.1, U1.10 (OUT), W1.1
GND: C1.2, C2.2, C3.2, J1.2, R1.2, R2.2, R4.2, U1.8 (GND), U1.11
unnamed: R2.1, U1.5 (ILIM)
unnamed: U1.9 (OUTS), W1.2
unnamed: R3.2, R4.1, U1.4 (PG)
unnamed: C2.1, R1.1, U1.7 (SET)

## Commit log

2025-10-02 add readme
    [control_board.kicad_pcb, control_board.kicad_sch]
2025-12-24 v2 board
    [Combo768USBC.step, control_board.kicad_pcb, control_board.kicad_sch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]
2026-01-08 add gerber and bom files
    [control_board-B_Courtyard.gbr, control_board-B_Cu.gbr, control_board-B_Mask.gbr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]
2026-01-08 add missing images
    [lpf_ak4497_dual.kicad_pcb, lpf_ak4497_dual_mono.kicad_pcb]
2026-01-08 fix lt3042 breakout
    [LT3042_breakout.kicad_pcb, LT3042_breakout.kicad_sch, LT3042_breakout_with_error_done.kicad_pcb]
